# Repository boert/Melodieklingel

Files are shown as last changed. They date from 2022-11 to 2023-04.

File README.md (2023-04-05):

# Melodieklingel

Leiterplatte für die Melodieklingel nach der Veröffentlichung von S. Lehmann im Funkamateur 4/86

## Eckdaten
Leiterplattengröße: 100 x 100 mm  
Betriebsspannung: 5V DC  
Stromaufnahme: 87 bis 230 mA (min./max.)  
Schaltschwelle (Transistor):   1,4 V  
Schaltschwelle (Optokoppler):  8 V (DC) oder 5,6 V (AC)    

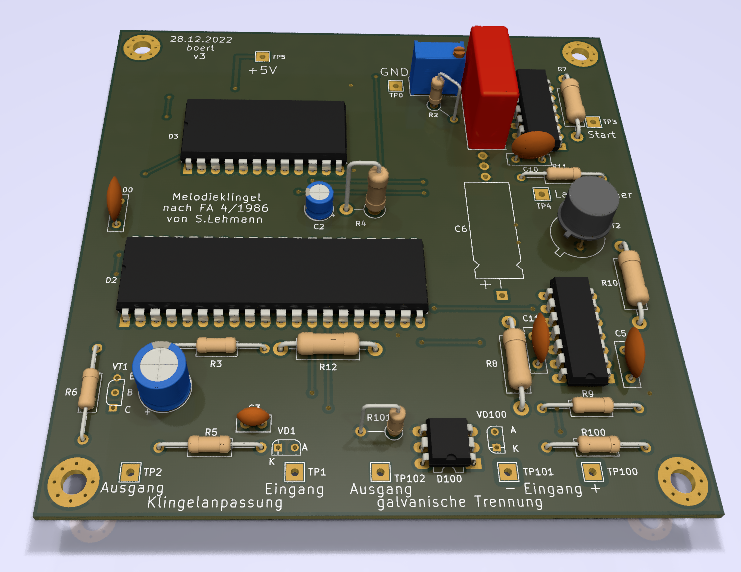
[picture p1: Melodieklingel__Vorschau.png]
3D-Vorschau


### Anschlüsse

| Name | Bedeutung | Bemerkung |
| ----- | --- | --- |
| TP 0 | GND/ Masse | |
| TP 1 | Eingang Transistorstufe | nicht potentialfrei, max. 24V Eingangsspannung |
| TP 2 | Ausgang Transistorstufe | muß ggf. mit TP3 verbunden werden |
| TP 3 | Taster | nicht potentialfrei, max. 5V Eingangsspannung |
| TP 4 | Lautsprecher | |
| TP 5 | +5V | |
| TP 100 | Eingang Optokoppler (+) | potentialfrei, max. 24V Eingangsspannung |
| TP 101 | Eingang Optokoppler (-) | potentialfrei, max. 24V Eingangsspannung |
| TP 102 | Ausgang Optokoppler | muß ggf. mit TP3 verbunden werden |

Der zweite Anschluss des Lautsprechers muß mit +5V (TP5) verbunden werden.

### Stromaufnahme

Alle Messungen erfolgten mit einem 8 Ohm-Kleinlautsprecher.

| Logikfamilie | IC D1 | IC D2 | IC D3 | IC D4 | Ruhezustand | Wiedergabe |
| --- | --- | --- | ----- | ---  | ---:| ---:|
| TTL | D104 | U880D | U2716 | D174 | 183 mA  (0,92 W) | 230 mA  (1,15 W) |
| CMOS | 74HCT04 | STZ8400 | U2716 | 74LS74  | 128 mA  (0,64 W) | 175 mA  (0,88 W) |
| CMOS | 74HCT04 | TMPZ84C00 | U2716 | 74LS74  |  87 mA  (0,44 W) | 135 mA  (0,68 W) | 

Hinweis: Da bei D4 nicht alle Eingänge beschaltet wurden, kann es beim Einsatz von 74HCT74 zu Fehlfunktionen kommen. Bei Verwendung von DL074/74LS74 sollte es keine Probleme geben.

## Änderungen gegenüber dem Original
- zusätzliche Bestückungsvariante mit Optokoppler zur galvanischen Trennung des Klingel
- Werte und Baugrößen an vorhandenen Lagerbestand angepasst
- alle liegenden Widerstände auf 15 mm Rastermaß geändert
- Stützkondensator für U880D ergänzt

## Bestückungsvarianten
### Taster
Dieser wird zwischen den Lötpunkten 'Start' und 'GND' angeschlossen.
Da keine galvansiche Trennung und Entstörung vorliegt, eignet sich diese Variante nur für denn Fall, das der Taster mit einer kurzen Leitung angschlossen wird, z.B. bei einer Montage im Gehäuse.

Folgende Bauteile können bei der Bestückung entfallen:  
C3, C4, R5, R6, VD1, VT1  
sowie:  
R100, R101, D100, VD100  

### Transistor
Bei dieser Variante hilft ein Tiefpass und ein Transistor beim Auslösen der Klingel. Es muß eine Verbindung zwischen TP2 und TP3 hergetellt werden.
Als Transistor für VT1 eignet sich jeder beliebige Kleinsignal-NPN-Typ, z.B. SC236, SF126, SF136, SF357, SS125, SS216.

Folgende Bauteile können bei der Bestückung entfallen:  
R100, R101, D100, VD100  

### Optokoppler
Hier wird ein Optokoppler zur galvaischen Trennung genutzt.
Um diese Variante zu Nutzen muß eine Verbindung zwischen TP102 und TP3 hergetellt werden.  
Zum Auslösen der Klingel dient die Gleich- oder Wechselspannung der vorhandenen Klingelanlage. Die Klingel wird mit einem Signal ab 8 V Gleichspannung oder ab 5,6 V Wechselspannung aktiviert. Über den Widerstand R100 kann die Schaltschwelle angepasst werden.  

Der Widerstand R7 sollte ggf. auf 47 kOhm erhöht werden, damit der Pegel am Gatter D1B passt.  
Folgende Bauteile können bei der Bestückung entfallen:  
C3, C4, R5, R6, VD1, VT1  

## Links
https://hc-ddr.hucki.net/wiki/doku.php/elektronik/melodieklingel

# Änderungen / History
## Version 3, 28.12.2022
- VT2, Footprint korrigiert (180° gedreht)

## Version 2, 29.11.2022
- C1 von 470 nF zu 470 pF geändert   
- D100, Pin 5 und Pin 6 getauscht

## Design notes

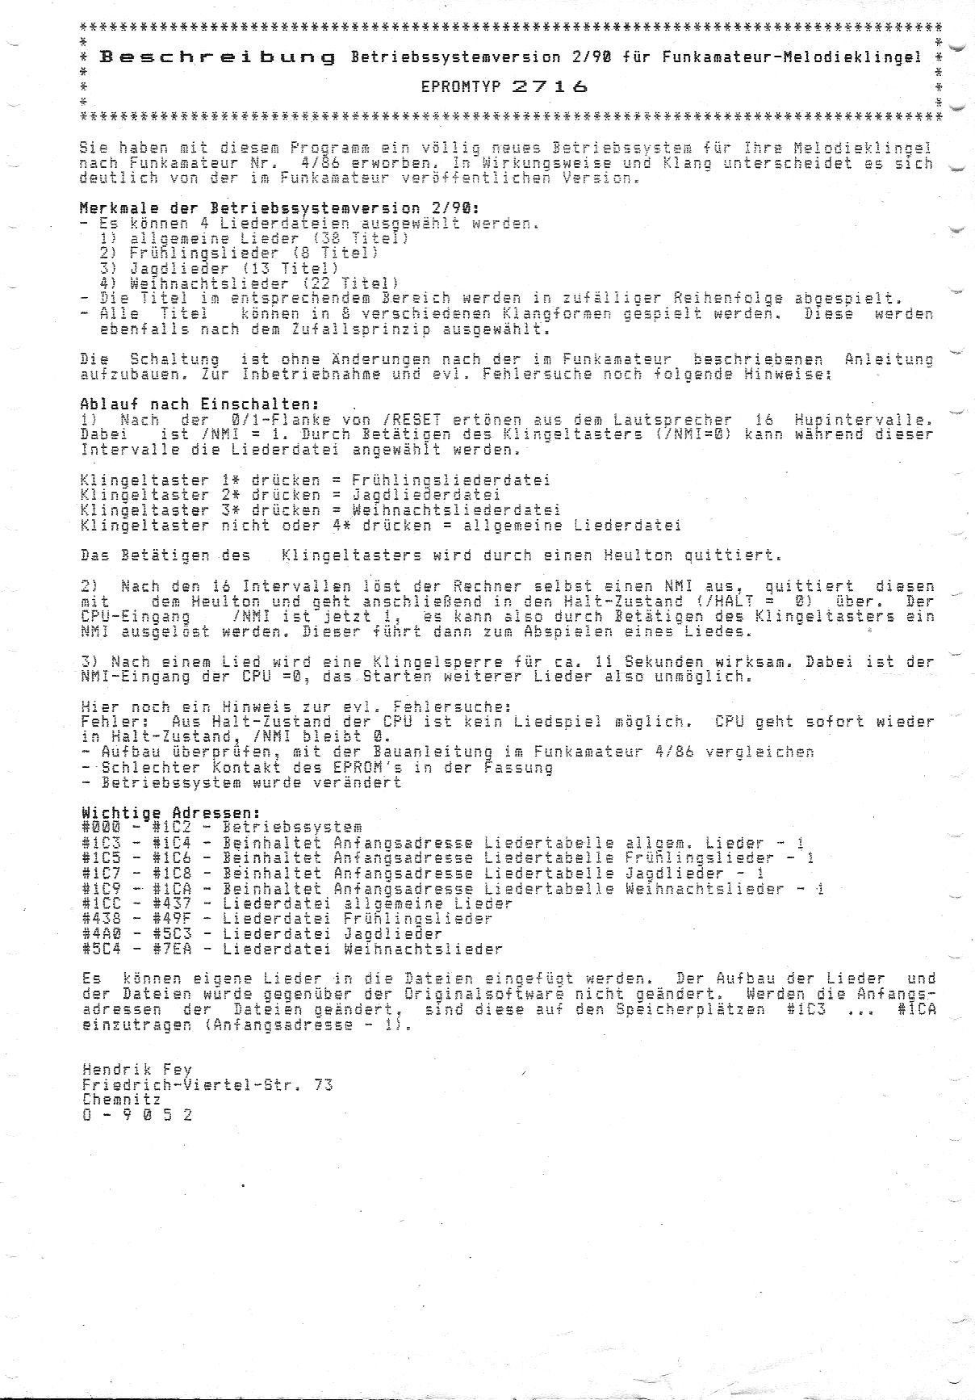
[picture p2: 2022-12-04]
EPROM-Inhalte/fey0290_Beschreibung.jpg

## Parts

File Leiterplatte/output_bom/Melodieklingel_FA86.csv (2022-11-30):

Source,Melodieklingel_FA86.kicad_sch
Kicad Rev,Eeschema (6.0.9)
Generated Date,Di 29 Nov 2022 21:24:32 CET
Title,Melodieklingel
Company,FA 4/86
Revision,2
Date Issue,29.11.22
Comment,boert
Reference,Value,Reference,Value,Library,Library Ref
C1,470pF,C1,470nF,Device,C_Small
C2,47µF,C2,47µF,Device,C_Polarized_Small
C3,10nF,Device,C_Small
C4,100µF,Device,C_Polarized_Small
C5,33nF,Device,C_Small
C6,10µF,Device,C_Polarized_Small
C10,33nF,Device,C_Small
C11,33nF,Device,C_Small
C100,33nF,Device,C_Small
D1,D104D,D1,D104D,RFT_Digitalschaltkreise,D104D
D2,U880D,D2,U880D,RFT_Digitalschaltkreise,U880D
D3,U2716,D3,U2716,RFT_Digitalschaltkreise,U2716
D4,D174D,D4,D174D,RFT_Digitalschaltkreise,D174D
D100,MB104,RFT_Optoelektronik,MB104
LS1,Lautsprecher,LS1,Lautsprecher,Device,Speaker
R1,100,R1,100,Device,R_Potentiometer_Small
R2,180,Device,R_Small
R3,330,Device,R_Small
R4,1,2k,Device,R_Small
R5,4,7k,Device,R_Small
R6,10k,Device,R_Small
R7,1k,Device,R_Small
R8,1k,Device,R_Small
R9,10k,Device,R_Small
R10,470,Device,R_Small
R11,11,Device,R_Small
R12,1,2k,R12,1,2k,Device,R_Small
R100,4,7k,Device,R_Small
R101,1M,Device,R_Small
SW1,Taster,SW1,Taster,Switch,SW_Push
VD1,SAY17,VD1,SAY17,Device,D_Small
VD100,SAY17,VD1,SAY17,Device,D_Small
VT1,NPN,RFT_Transistoren_und_Dioden,SF126
VT2,SF126,VT2,SF126,RFT_Transistoren_und_Dioden,SF126

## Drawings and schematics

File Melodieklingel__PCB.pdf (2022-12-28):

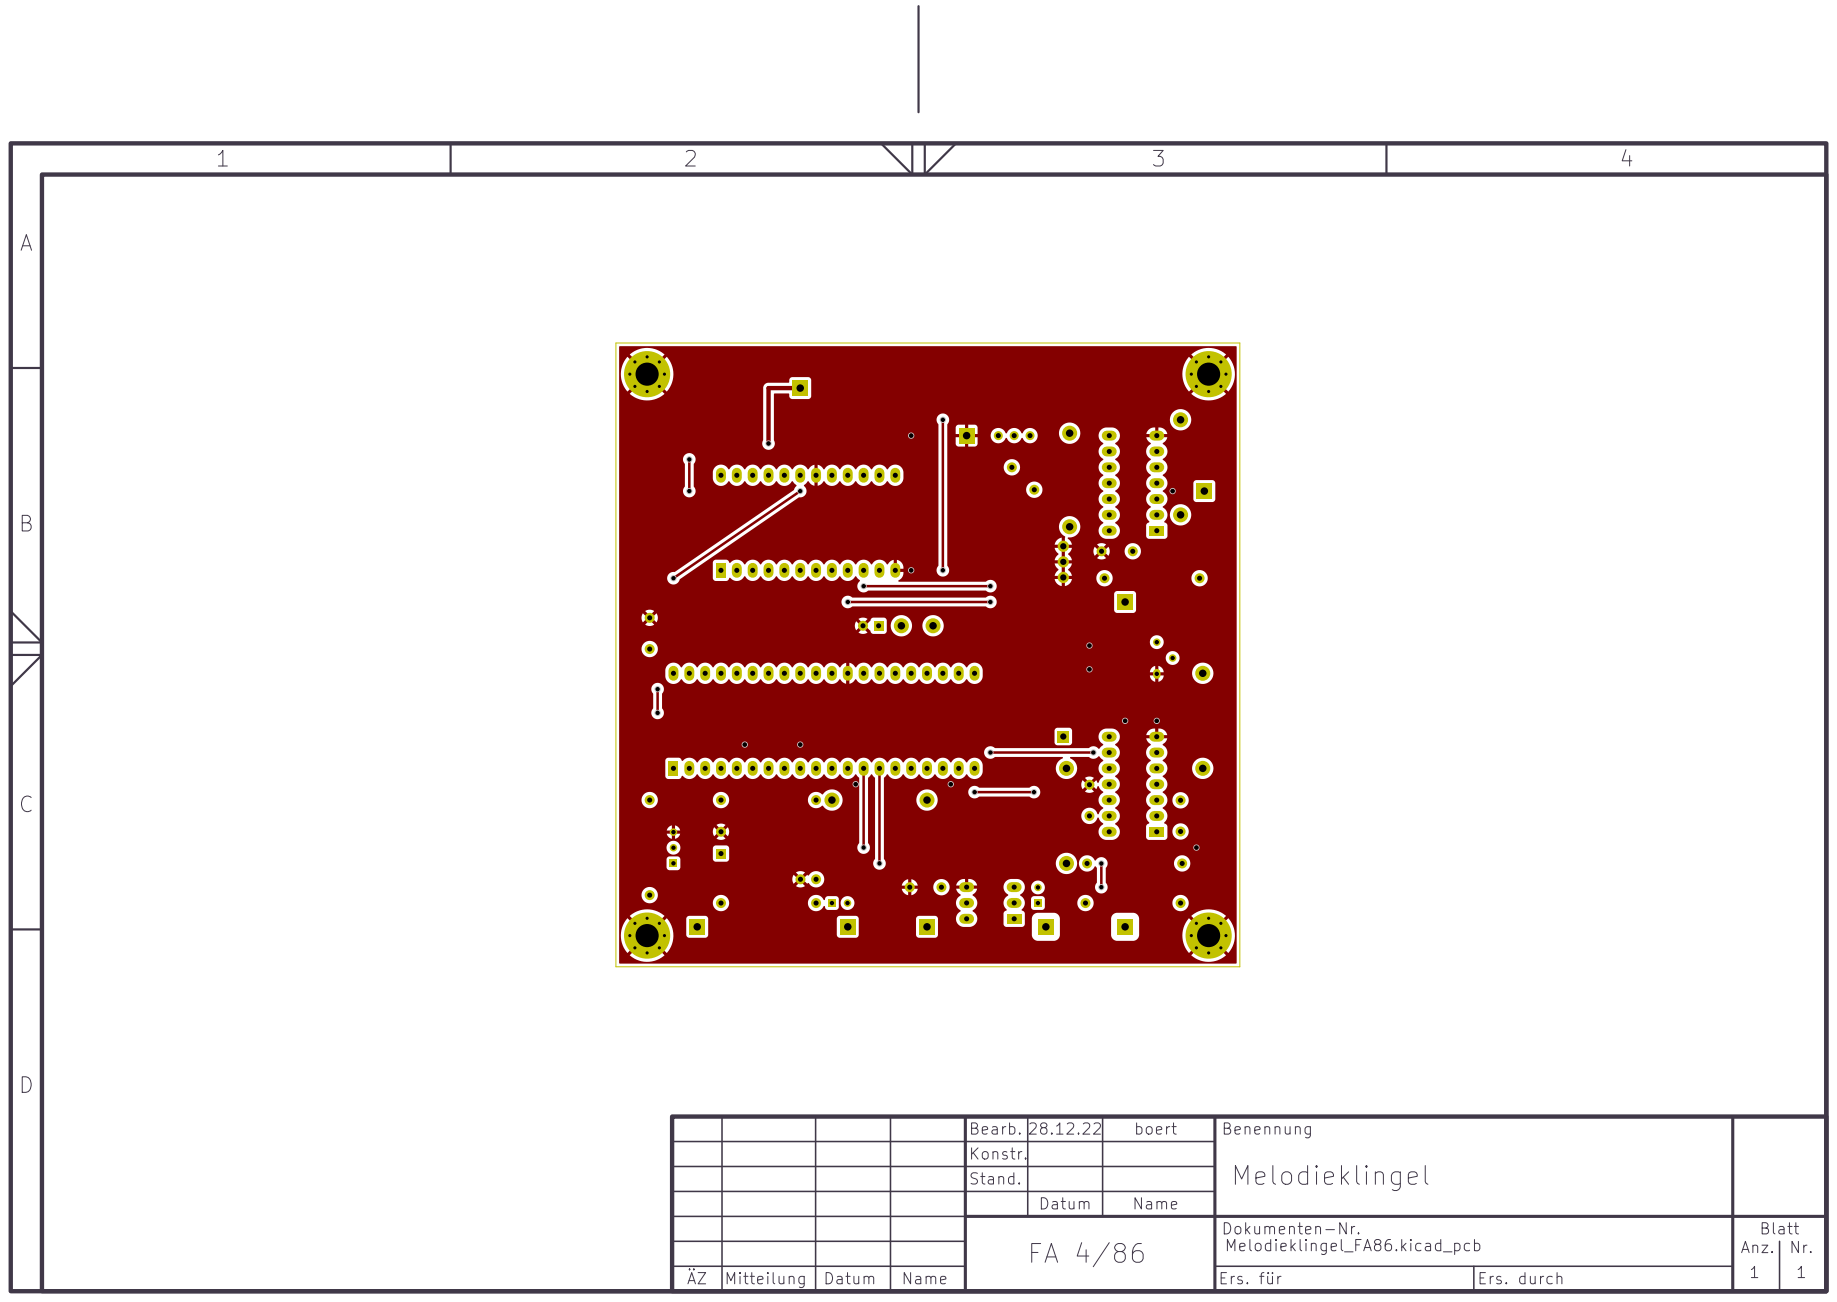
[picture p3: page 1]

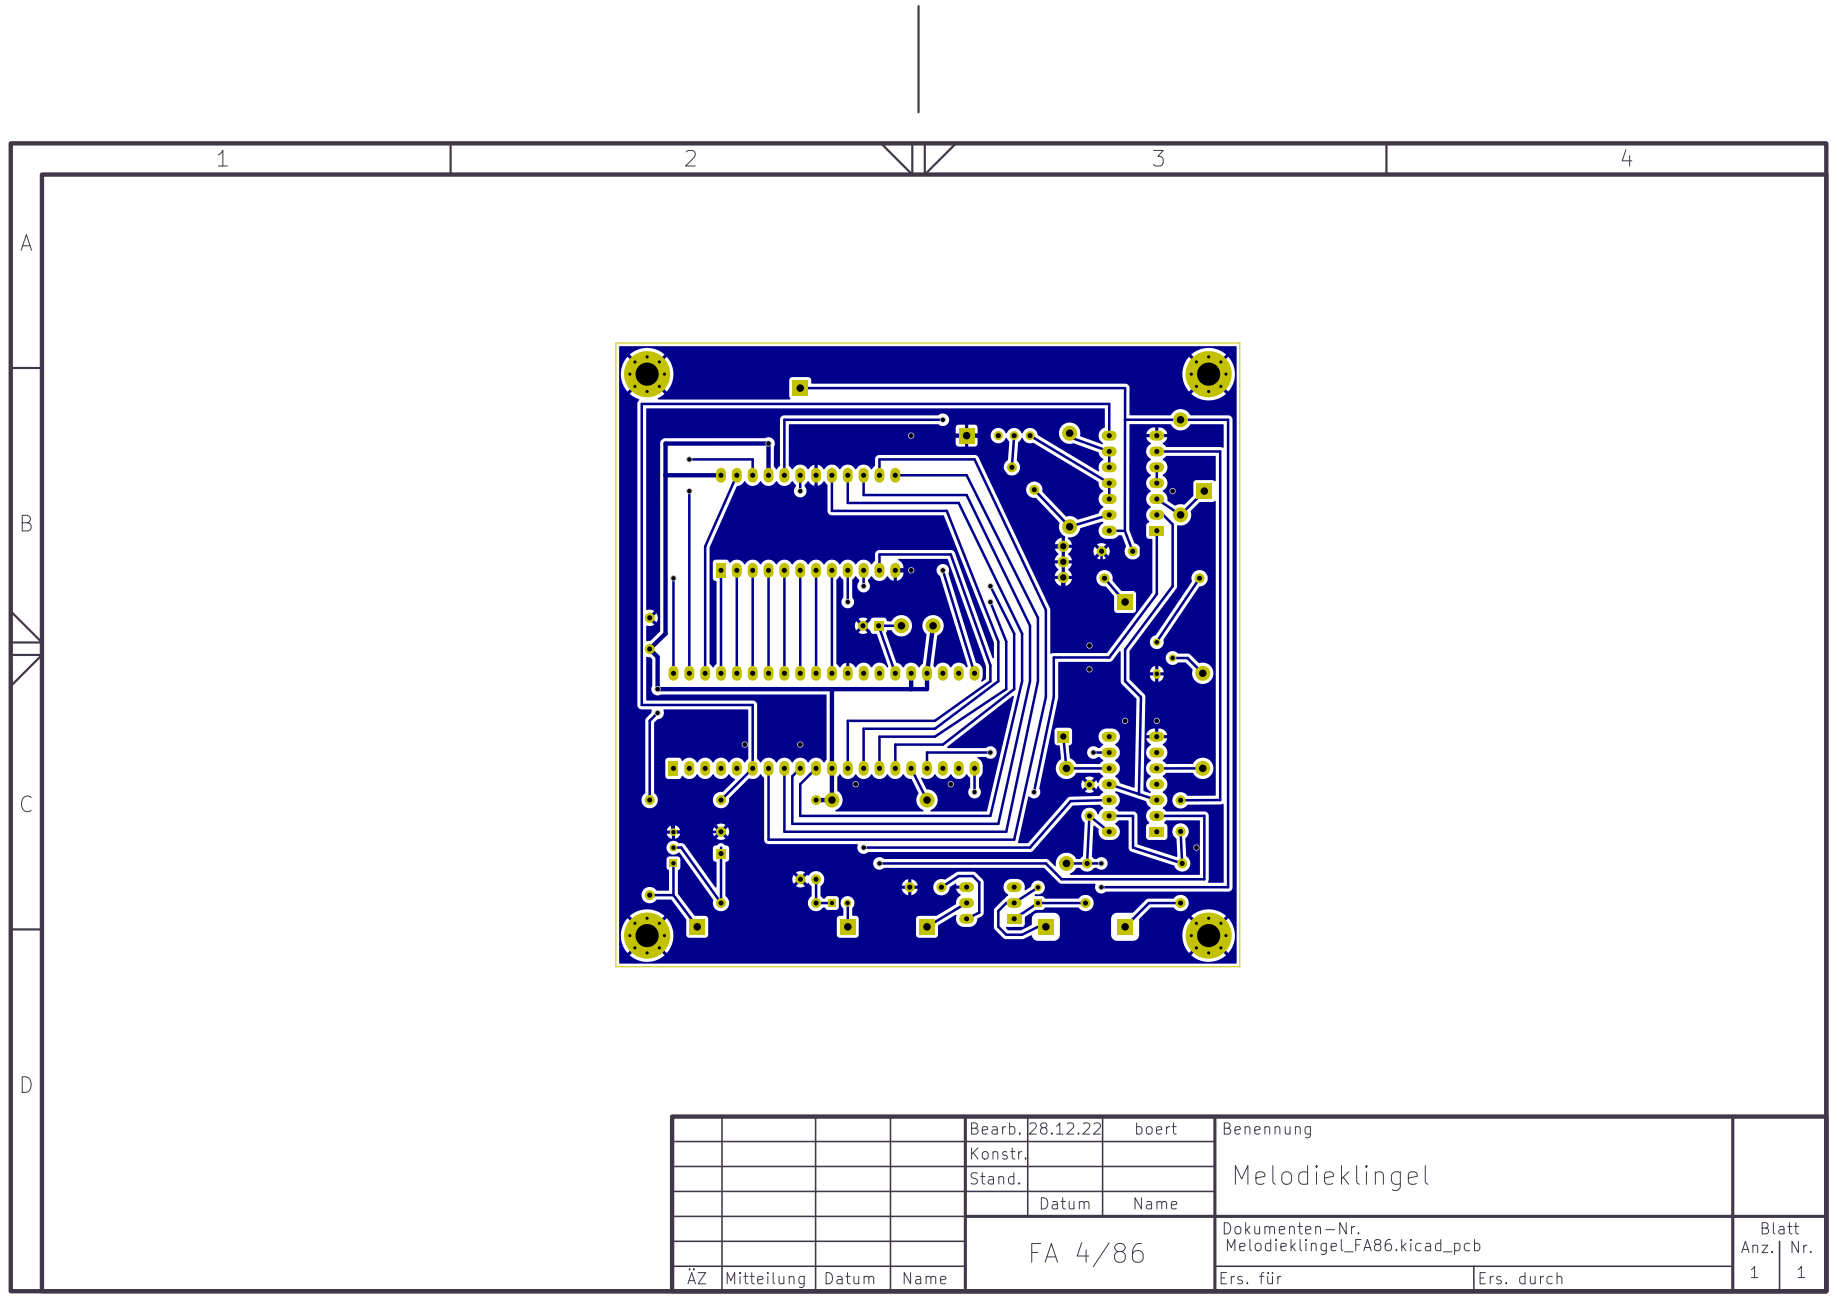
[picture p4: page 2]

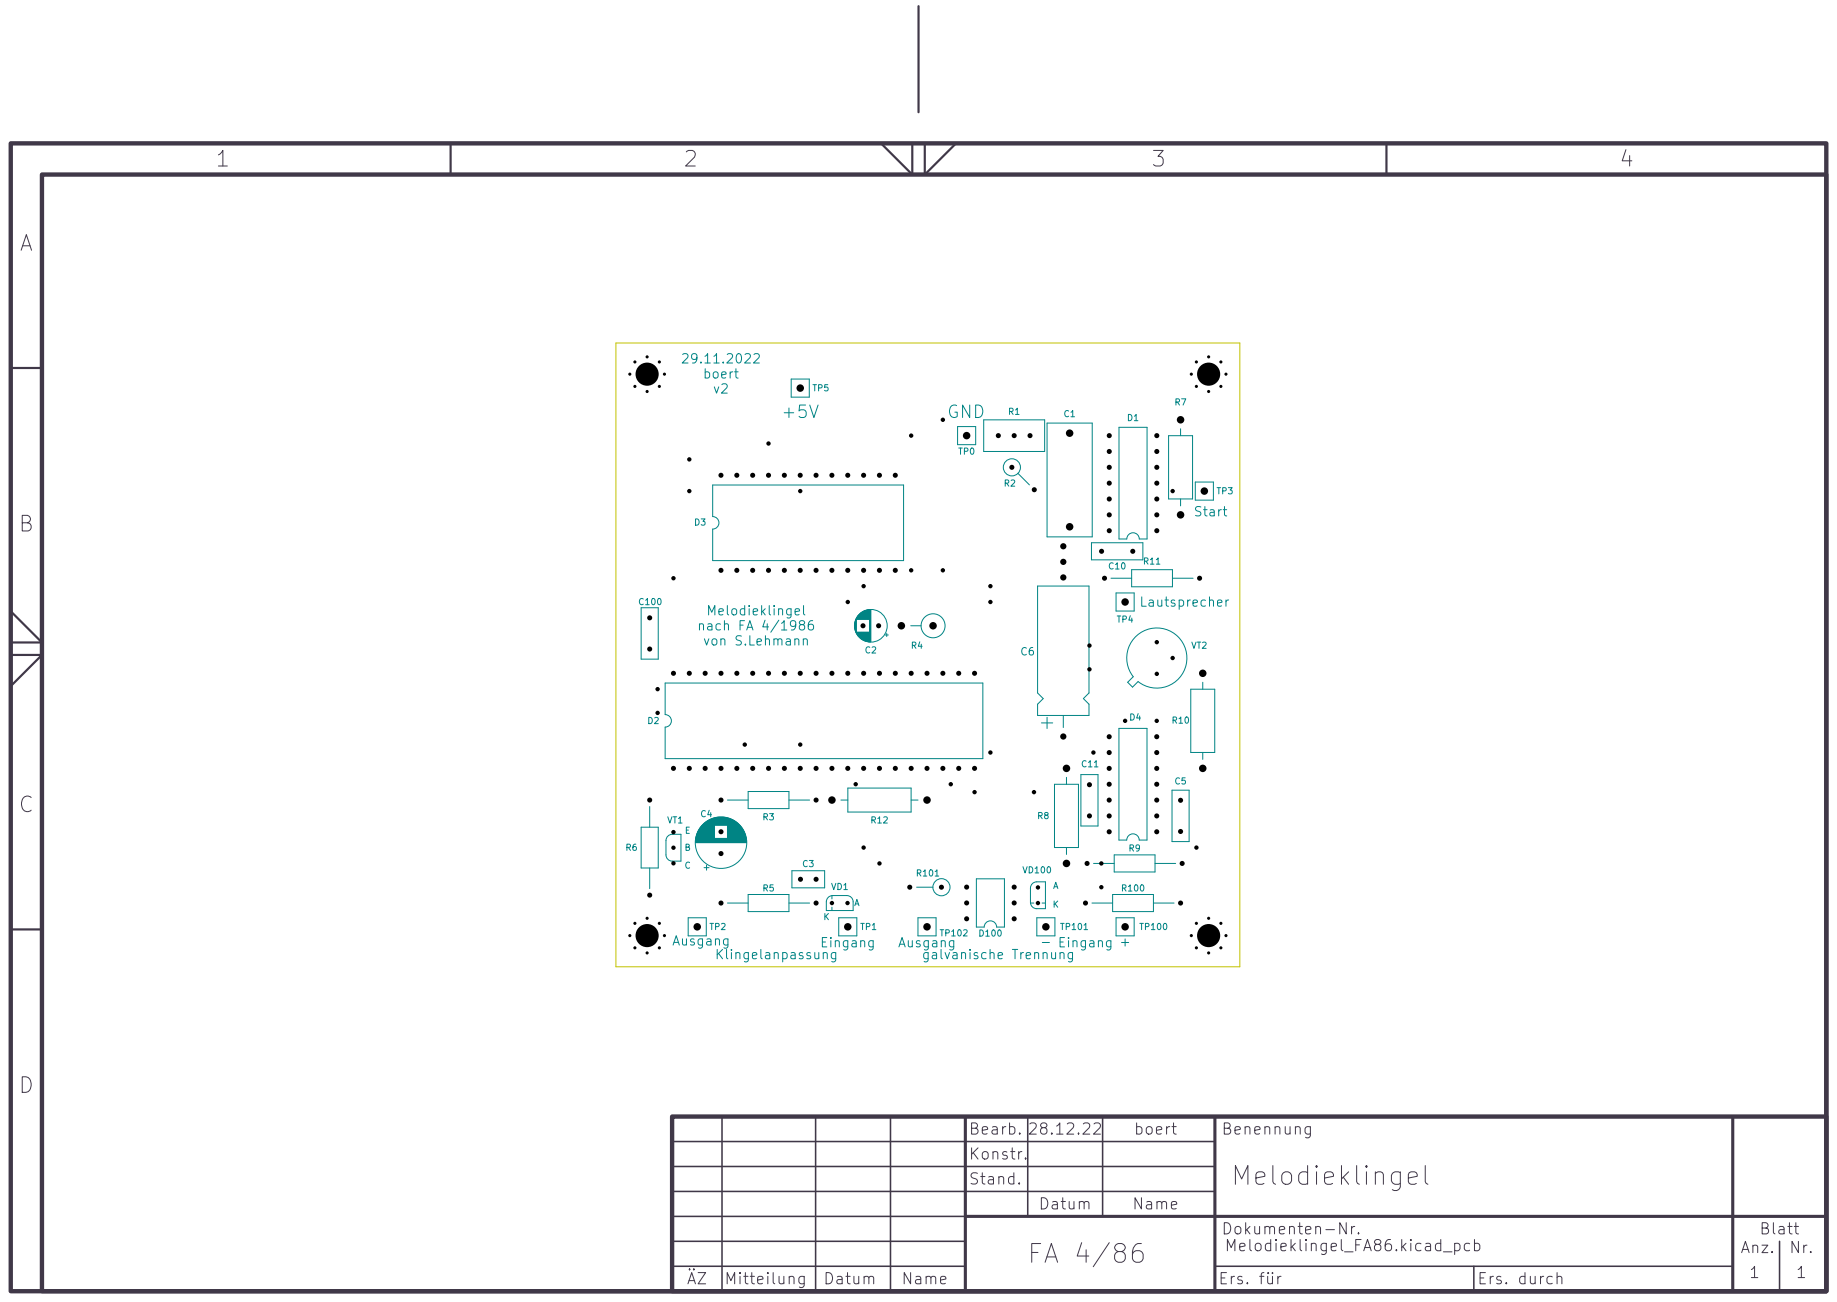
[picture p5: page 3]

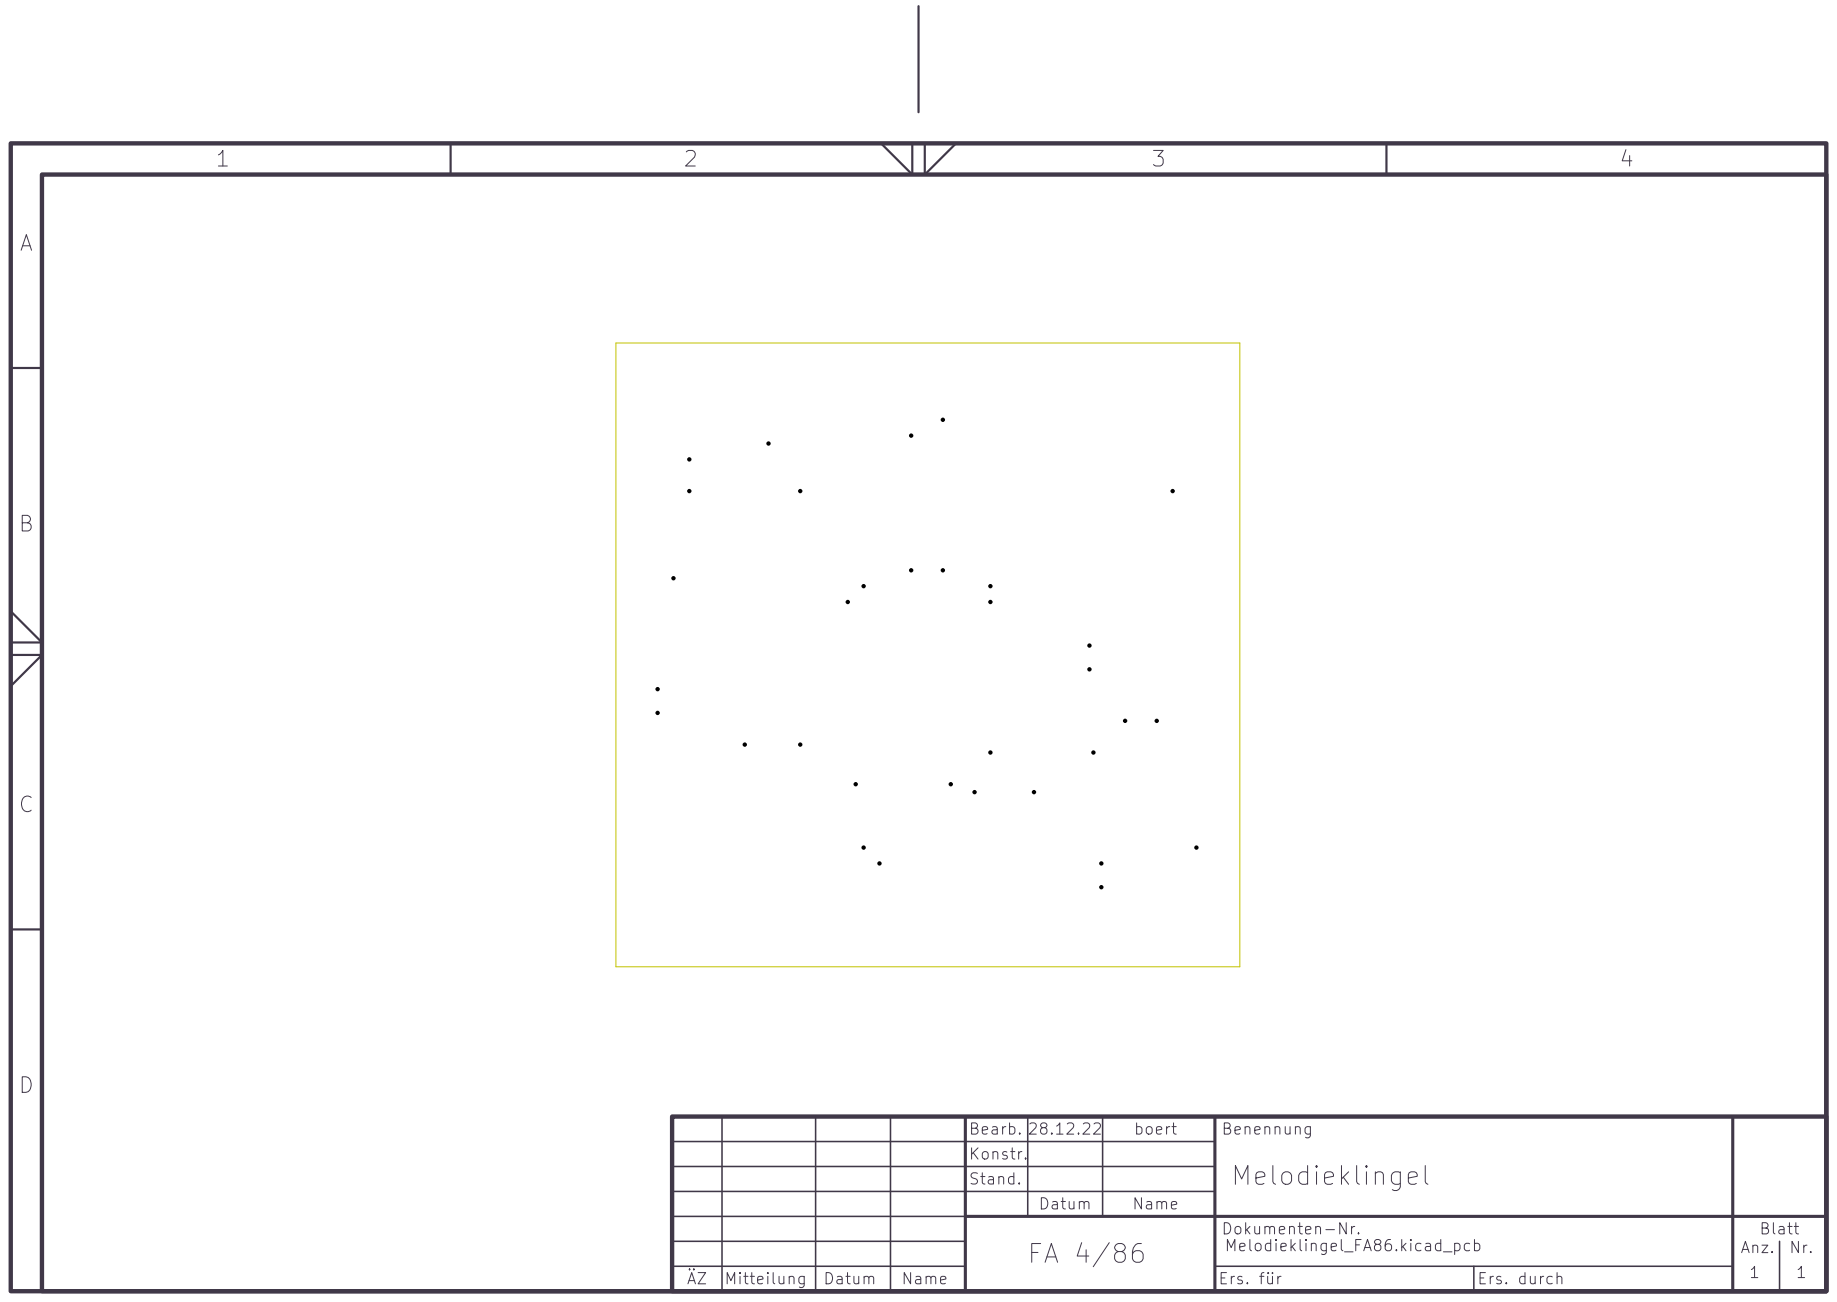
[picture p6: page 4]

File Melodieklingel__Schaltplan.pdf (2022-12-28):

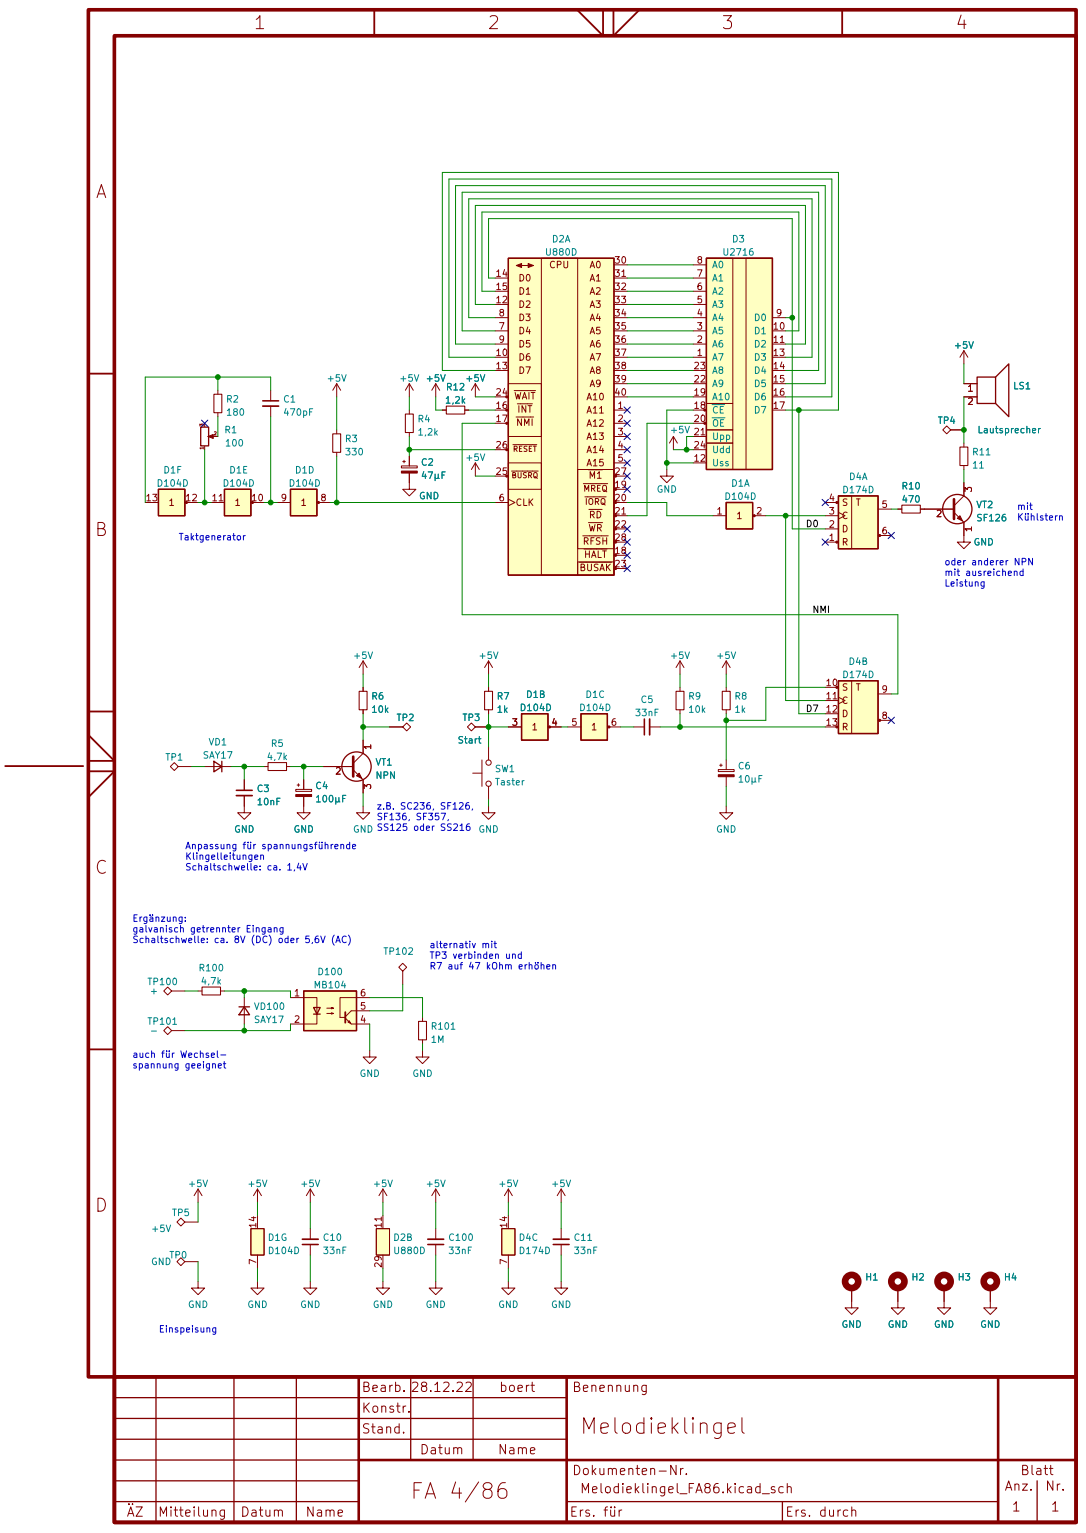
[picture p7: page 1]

oder anderer NPN mit ausreichend

S C D R | T
11

alternativ mit TP3 verbinden und

Datum | Name

Dokumenten-Nr. | Blatt

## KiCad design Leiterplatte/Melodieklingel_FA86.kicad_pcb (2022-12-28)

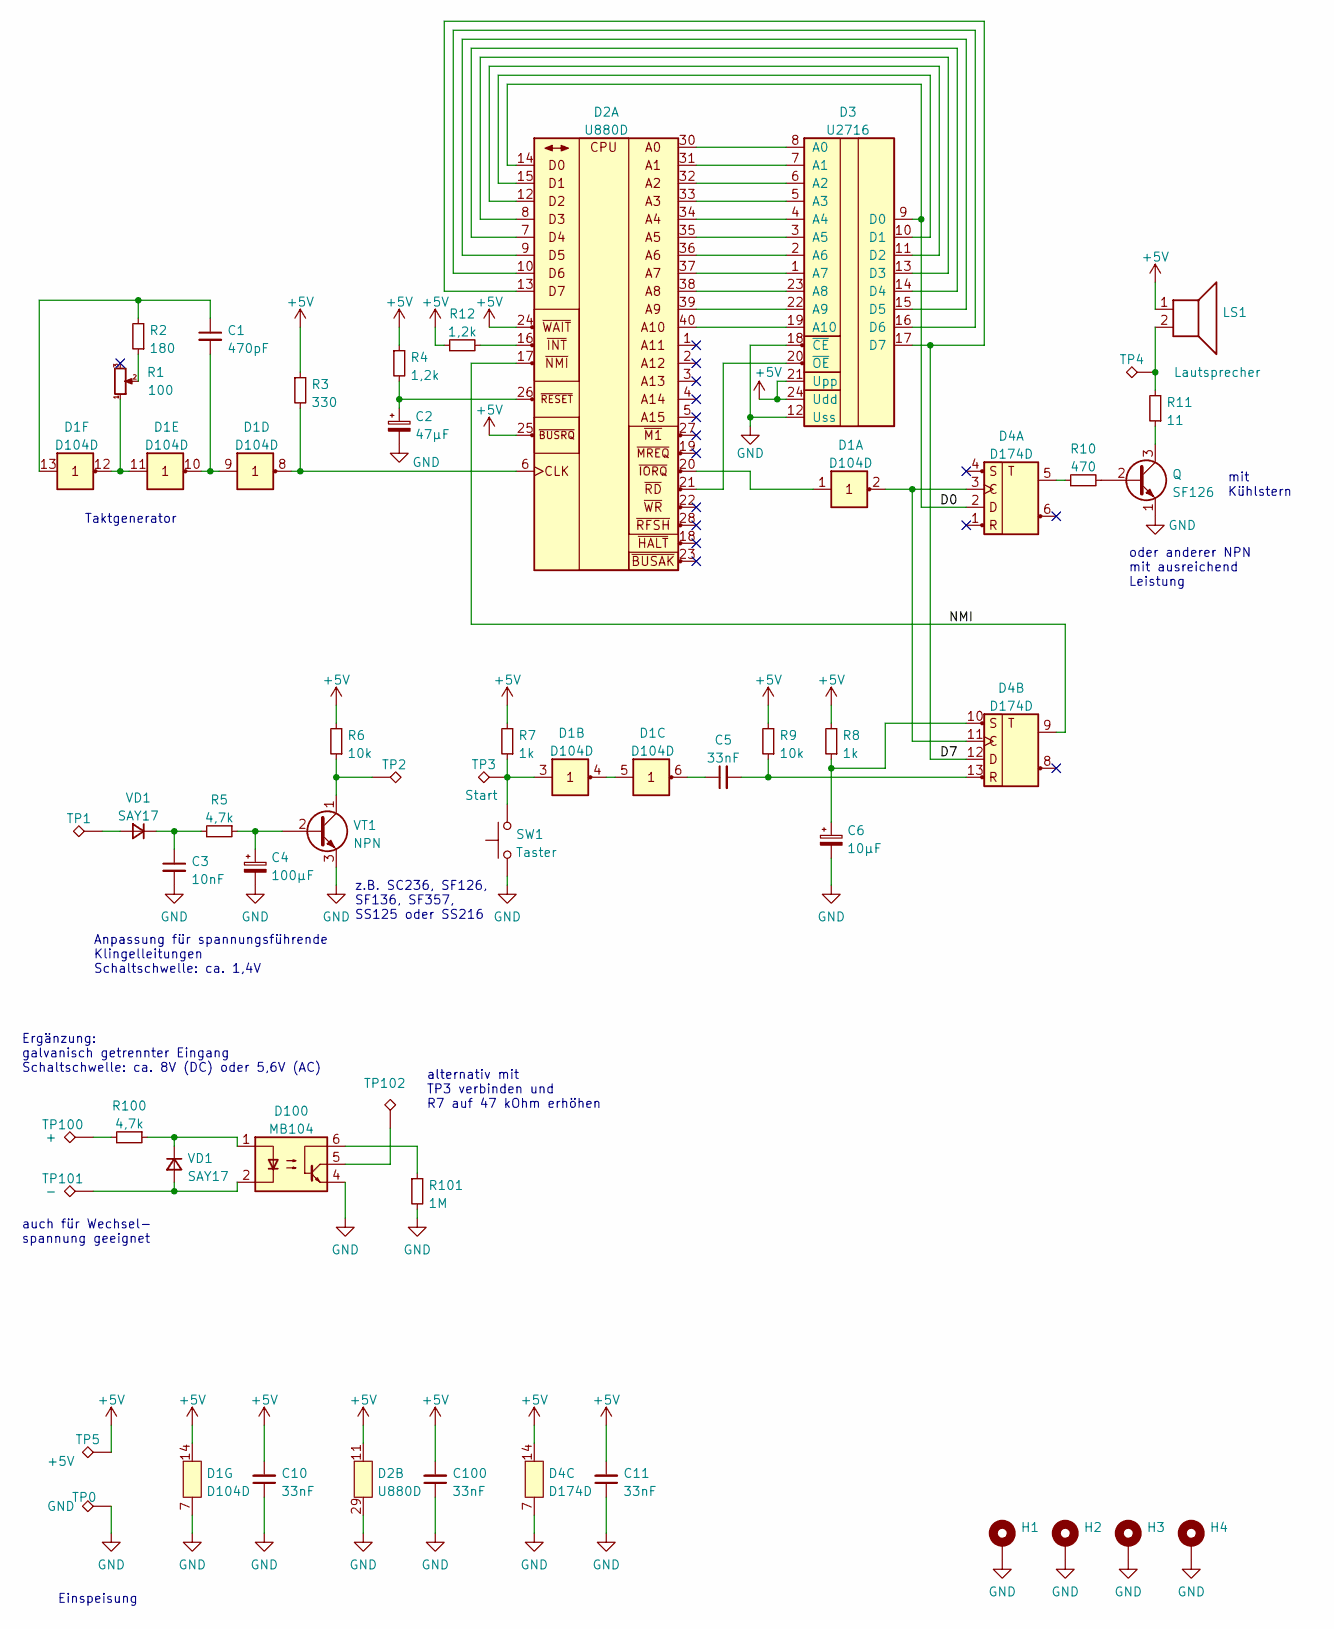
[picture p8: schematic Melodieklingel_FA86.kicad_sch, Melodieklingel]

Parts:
C1: 470nF; C_Rect_L18.0mm_W7.0mm_P15.00mm_FKS3_FKP3
C2: 47µF; CP_Radial_D5.0mm_P2.50mm
C3: 10nF; C_Disc_D5.0mm_W2.5mm_P2.50mm
C4: 100µF; CP_Radial_D8.0mm_P3.50mm
C5, C10, C11, C100: 33nF; C_Disc_D8.0mm_W2.5mm_P5.00mm
C6: 10µF; CP_Axial_L21.0mm_D8.0mm_P28.00mm_Horizontal
D1: D104D; DIP-14_W7.62mm_LongPads
D2: U880D; DIP-40_W15.24mm_LongPads
D3: U2716; DIP-24_W15.24mm_LongPads
D4: D174D; DIP-14_W7.62mm_LongPads
D100: MB104; DIP-6_W7.62mm_LongPads
H1, H2, H3, H4: MountingHole_Pad; MountingHole_3.7mm_Pad_Via
LS1: Lautsprecher
Q: SF126; TO-5-3
R1: 100; Potentiometer_Bourns_3296W_Vertical
R2: 180; R_Axial_DIN0207_L6.3mm_D2.5mm_P5.08mm_Vertical
R3: 330; R_Axial_DIN0207_L6.3mm_D2.5mm_P15.24mm_Horizontal
R4: 1,2k; R_Axial_DIN0411_L9.9mm_D3.6mm_P5.08mm_Vertical
R5, R100: 4,7k; R_Axial_DIN0207_L6.3mm_D2.5mm_P15.24mm_Horizontal
R6, R9: 10k; R_Axial_DIN0207_L6.3mm_D2.5mm_P15.24mm_Horizontal
R7, R8: 1k; R_Axial_DIN0411_L9.9mm_D3.6mm_P15.24mm_Horizontal
R10: 470; R_Axial_DIN0411_L9.9mm_D3.6mm_P15.24mm_Horizontal
R11: 11; R_Axial_DIN0207_L6.3mm_D2.5mm_P15.24mm_Horizontal
R12: 1,2k; R_Axial_DIN0411_L9.9mm_D3.6mm_P15.24mm_Horizontal
R101: 1M; R_Axial_DIN0207_L6.3mm_D2.5mm_P5.08mm_Vertical
SW1: Taster
TP0: GND; TestPoint_THTPad_2.5x2.5mm_Drill1.2mm
TP1: Eingang; TestPoint_THTPad_2.5x2.5mm_Drill1.2mm
TP2, TP102: Ausgang; TestPoint_THTPad_2.5x2.5mm_Drill1.2mm
TP3: Start; TestPoint_THTPad_2.5x2.5mm_Drill1.2mm
TP4: Lautsprecher; TestPoint_THTPad_2.5x2.5mm_Drill1.2mm
TP5: +5V; TestPoint_THTPad_2.5x2.5mm_Drill1.2mm
TP100: +; TestPoint_THTPad_2.5x2.5mm_Drill1.2mm
TP101: -; TestPoint_THTPad_2.5x2.5mm_Drill1.2mm
VD1: SAY17; D_E-Line_P2.5mm_Vertical
VT1: NPN; T_E-Line_Wide_P2.5mm_Vertical

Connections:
+5V: C10.2, C11.2, C100.2, D1.14 (Vcc), D2.11 (Vcc), D2.24 (~WAIT), D2.25 (~BUSRQ), D3.21 (Upp), D3.24 (Udd), D4.14 (Vcc), LS1.1, R3.1, R4.1, R6.2, R7.2, R8.2, R9.2, R12.1, TP5.1
/D0: D2.14 (D0), D3.9 (D0), D4.2 (D1)
/D7: D2.13 (D7), D3.17 (D7), D4.12 (D2)
/NMI: D2.17 (~NMI), D4.9 (Q2)
GND: C2.2, C3.2, C4.2, C6.2, C10.1, C11.1, C100.1, D1.7 (GND), D2.29 (GND), D3.12 (Uss), D3.18 (~CE), D4.7 (GND), D100.4, H1.1, H2.1, H3.1, H4.1, Q.1 (E), R101.2, SW1.1, TP0.1, VT1.3 (E)
unnamed: C1.1, D1.13 (A6), R2.2
unnamed: C1.2, D1.9 (A4), D1.10 (Y5)
unnamed: C2.1, D2.26 (~RESET), R4.2
unnamed: C4.1, R5.1, VT1.2 (B)
unnamed: C5.1, D1.6 (Y3)
unnamed: C5.2, D4.13 (R2), R9.1
unnamed: C6.1, D4.10 (S2), R8.1
unnamed: D1.1 (A1), D2.20 (~IORQ)
unnamed: D1.2 (Y1), D4.3 (T1), D4.11 (T2)
unnamed: D1.3 (A2), R7.1, SW1.2, TP3.1
unnamed: D1.4 (Y2), D1.5 (A3)
unnamed: D1.8 (Y4), D2.6 (CLK), R3.2
unnamed: D1.11 (A5), D1.12 (Y6), R1.1
unnamed: D2.7 (D4), D3.14 (D4)
unnamed: D2.8 (D3), D3.13 (D3)
unnamed: D2.9 (D5), D3.15 (D5)
unnamed: D2.10 (D6), D3.16 (D6)
unnamed: D2.12 (D2), D3.11 (D2)
unnamed: D2.15 (D1), D3.10 (D1)
unnamed: D2.16 (~INT), R12.2
unnamed: D2.21 (~RD), D3.20 (~OE)
unnamed: D2.30 (A0), D3.8 (A0)
unnamed: D2.31 (A1), D3.7 (A1)
unnamed: D2.32 (A2), D3.6 (A2)
unnamed: D2.33 (A3), D3.5 (A3)
unnamed: D2.34 (A4), D3.4 (A4)
unnamed: D2.35 (A5), D3.3 (A5)
unnamed: D2.36 (A6), D3.2 (A6)
unnamed: D2.37 (A7), D3.1 (A7)
unnamed: D2.38 (A8), D3.23 (A8)
unnamed: D2.39 (A9), D3.22 (A9)
unnamed: D2.40 (A10), D3.19 (A10)
unnamed: D4.5 (Q1), R10.1
unnamed: D100.5, TP102.1
unnamed: D100.6, R101.1
unnamed: LS1.2, R11.2, TP4.1
unnamed: R1.2, R2.1
unnamed: R6.1, TP2.1, VT1.1 (C)
unnamed: Q.2 (B), R10.2
unnamed: Q.3 (C), R11.1
unnamed: R100.2, TP100.1

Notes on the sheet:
auch für Wechsel- spannung geeignet
Ergänzung: galvanisch getrennter Eingang Schaltschwelle: ca. 8V (DC) oder 5,6V (AC)
mit Kühlstern
Einspeisung
oder anderer NPN mit ausreichend Leistung
alternativ mit TP3 verbinden und R7 auf 47 kOhm erhöhen
Anpassung für spannungsführende Klingelleitungen Schaltschwelle: ca. 1,4V
Taktgenerator
z.B. SC236, SF126, SF136, SF357, SS125 oder SS216

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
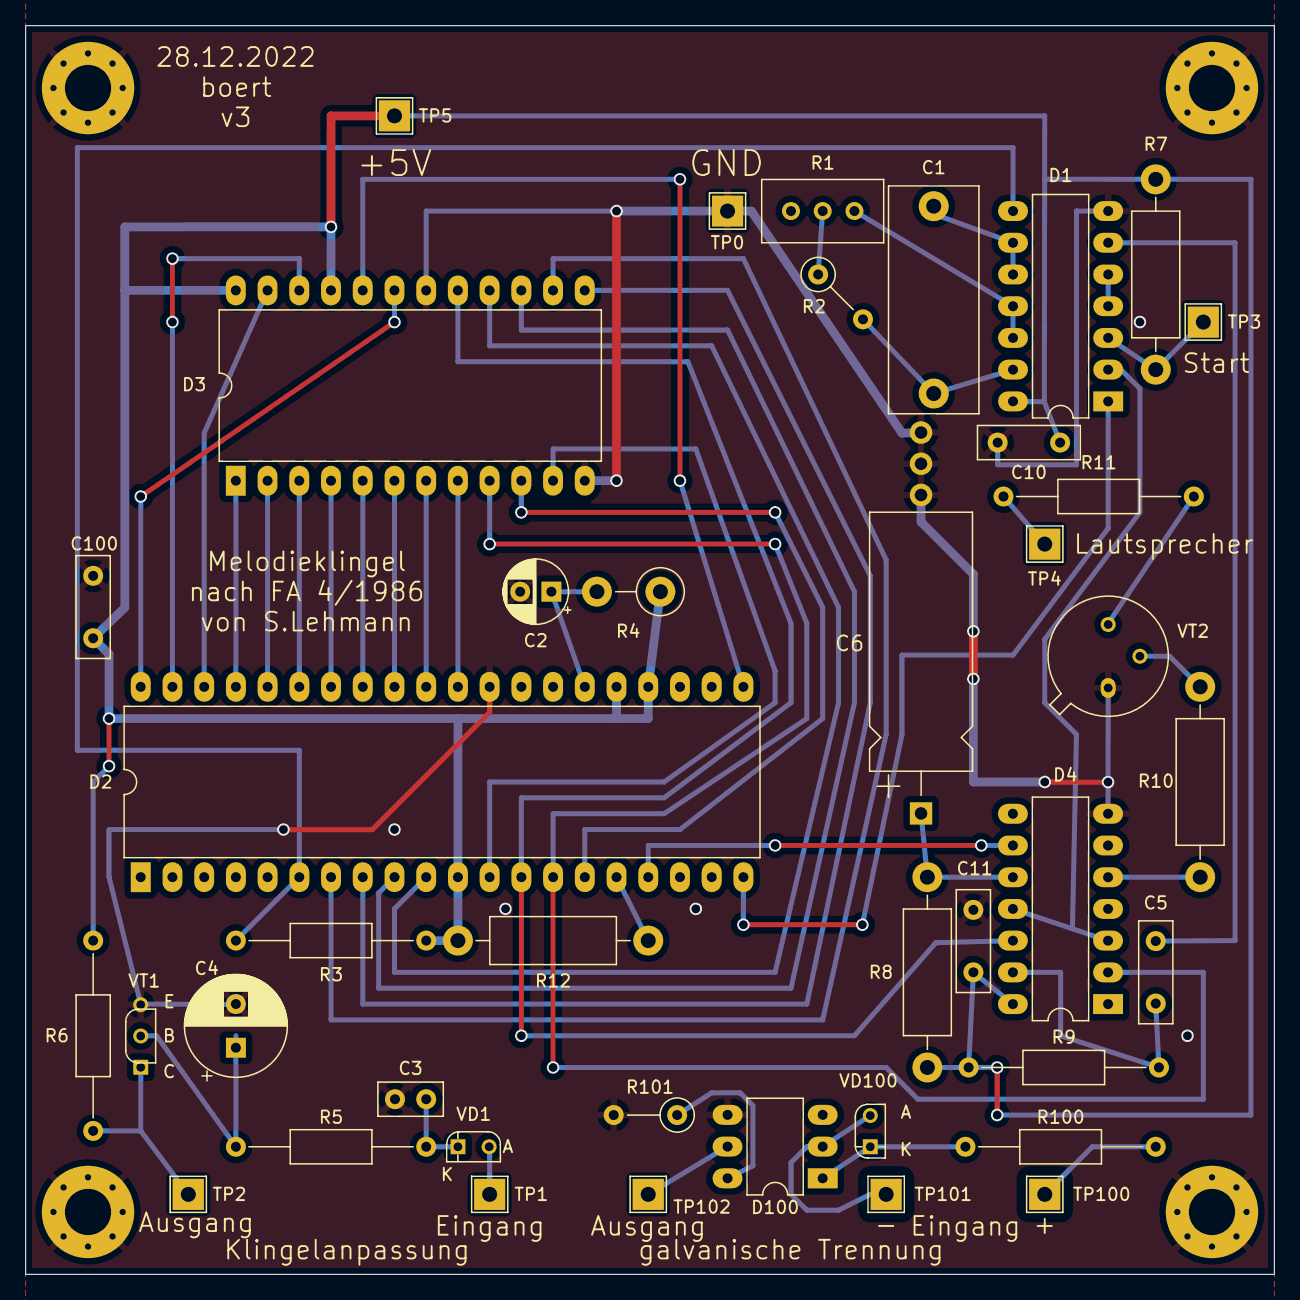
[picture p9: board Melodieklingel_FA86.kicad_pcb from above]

Board: 2 copper layers, 100.0 x 100.0 mm, 45 parts (0 on the bottom side), 50 nets.

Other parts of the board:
VD1#2: SAY17; D_E-Line_P2.5mm_Vertical

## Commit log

2022-11-16 Leiterplattenprojekt ergänzt
    [Melodieklingel_FA86-B_Cu.gbr, Melodieklingel_FA86-B_Mask.gbr, Melodieklingel_FA86-B_Paste.gbr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]
2022-11-30 Leiterplatte v2, mit Korrekturen
    [Melodieklingel_FA86-B_Cu.gbr, Melodieklingel_FA86-B_Mask.gbr, Melodieklingel_FA86-B_Paste.gbr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]
2022-12-28 fix: VT2, Footprint
    [Melodieklingel_FA86-B_Cu.gbr, Melodieklingel_FA86-B_Mask.gbr, Melodieklingel_FA86-B_Paste.gbr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]
